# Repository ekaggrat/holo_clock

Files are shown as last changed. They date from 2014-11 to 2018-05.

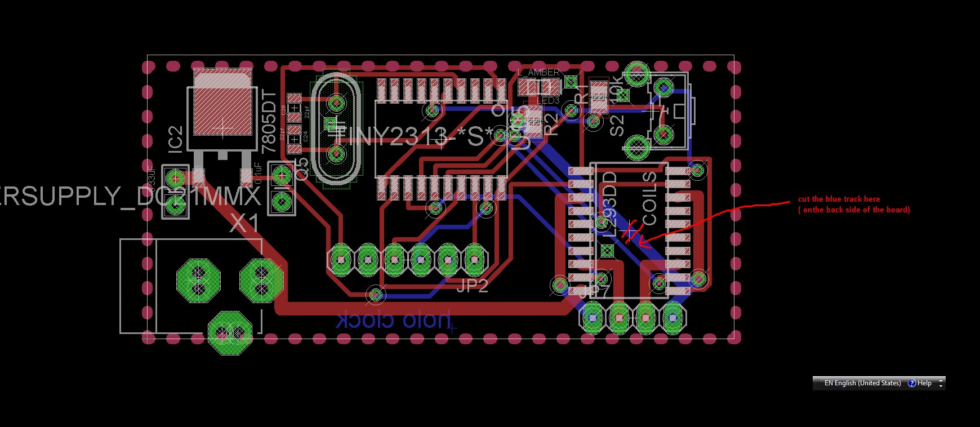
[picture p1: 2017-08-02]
pcb error.jpg

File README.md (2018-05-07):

View this project on [CADLAB.io](https://cadlab.io/node/990). 

holo_clock
==========
arduino and pcb files for holo clock

published
http://hackaday.com/2014/12/01/3d-printed-clock-tells-time-with-gears/

3d files here
http://www.thingiverse.com/thing:570797

for sale here
https://www.tindie.com/products/ekaggrat/holo-clock-2/

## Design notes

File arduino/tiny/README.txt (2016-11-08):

Arduino-Tiny is an open source set of ATtiny "cores" for the Arduino platform.

The Arduino platform currently supports Atmel ATmega processors. There is a need
for the Arduino platform to work with physically smaller DIP package processors.
The intent of this project is fulfill that need. Specifically, our goal is to
provide a core that enables Arduino users to work with the ATtiny84 (84/44/24),
ATtiny85 (85/45/25), and ATtiny2313 processors.

For more information about Arduino, see the website at: http://www.arduino.cc/

INSTALLATION

First ensure the Arduino software is correctly installed.

Next...

* Ensure the Arduino IDE is NOT running.

* Download the Arduino-Tiny archive (ZIP-file).

* Locate the Arduino Sketchbook folder.  This is the folder where the Arduino 
  IDE stores Sketches.

* Ensure the "hardware" folder exists under the Arduino Sketchbook folder.  For
  example, if the Arduino Sketchbook folder is...

      C:\Projects\Arduino\

  Ensure this folder exists...

      C:\Projects\Arduino\hardware\

* Extract the contents of the archive into the "hardware" folder.  For example,
  if the Arduino Sketchbook folder is...

      C:\Projects\Arduino

  After extracting, the following files / folders should exist...

      C:\Projects\Arduino\hardware\tiny\avr\license.txt
      C:\Projects\Arduino\hardware\tiny\avr\platform.txt
      C:\Projects\Arduino\hardware\tiny\avr\Prospective Boards.txt
      C:\Projects\Arduino\hardware\tiny\avr\README
      C:\Projects\Arduino\hardware\tiny\avr\bootloaders\
      C:\Projects\Arduino\hardware\tiny\avr\cores\

  The following folder should contain the source files for the Arduino-Tiny
  core...

      C:\Projects\Arduino\hardware\tiny\avr\cores\tiny\

* Create a new file named "boards.txt" in the tiny\avr directory.  Following 
  from the examples above, the file would be here...

      C:\Projects\Arduino\hardware\tiny\avr\boards.txt

* Open the "boards.txt" file and the "Prospective Boards.txt" file using your
  favourite text editor.

* Copy board entries of interest from "Prospective Boards.txt" to "boards.txt"
  (or copy the entire contents of "Prospective Boards.txt" to "boards.txt").
  Board entries are delineated by a long line of pound-signs.

* In the "boards.txt" file, change the "upload.tool" entries to the
  appropriate value for your setup.

* Save and close "boards.txt".  Close "Prospective Boards.txt".

* Start the Arduino IDE and ensure the new boards of interest are listed under
  the [Tools] [Board] menu...

      "ATtiny84 @ 16 MHz  (external crystal; 4.3 V BOD)"
      "ATtiny85 @ 8 MHz  (internal oscillator; BOD disabled)"
      etcetera

You are now ready to use Arduino-Tiny!

CREDITS

Arduino is an open source project, supported by many.

The Arduino team is composed of Massimo Banzi, David Cuartielles, Tom Igoe,
Gianluca Martino, and David A. Mellis.

Arduino uses the GNU avr-gcc toolchain, avrdude, avr-libc, and code from
Processing and Wiring.

Arduino-Tiny is based on work by David A. Mellis, René Bohne, R. Wiersma,
Alessandro Saporetti, and Brian Cook.

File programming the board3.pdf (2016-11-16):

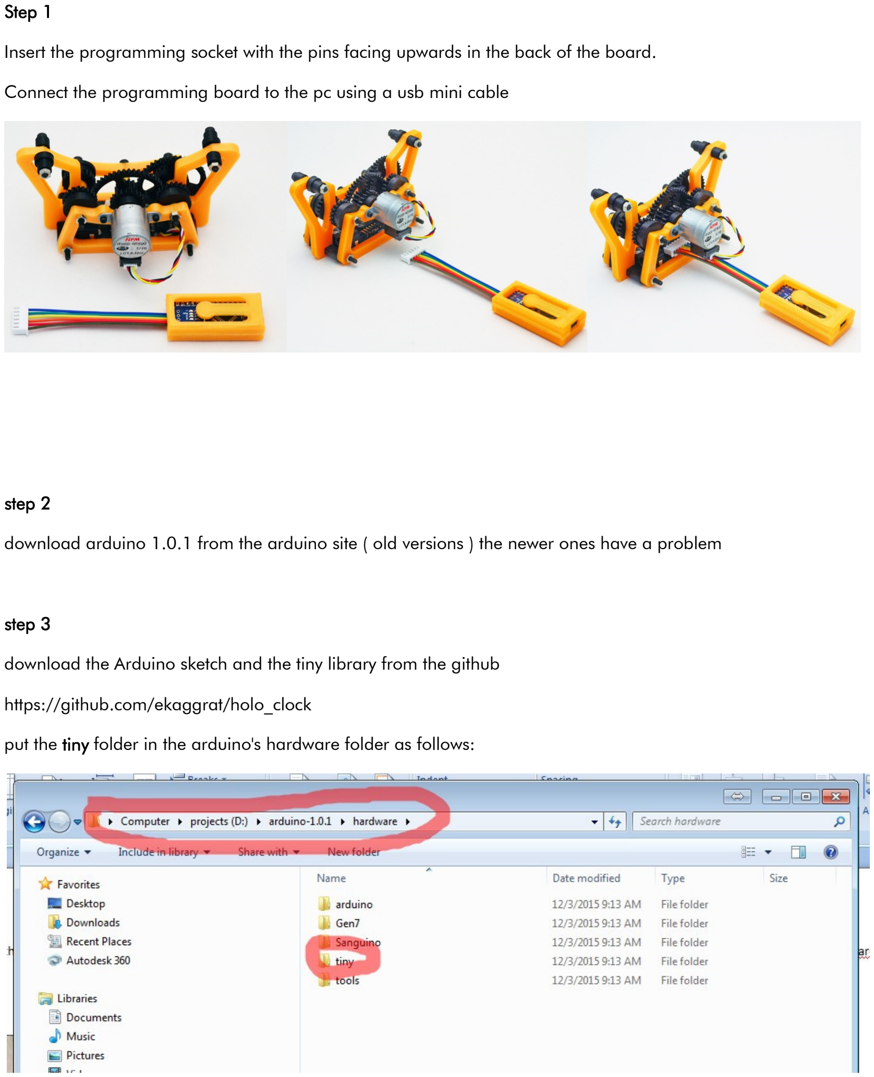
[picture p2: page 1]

Step 1

Insert the programming socket with the pins facing upwards in the back of the board.

Connect the programming board to the pc using a usb mini cable

step 2

download arduino 1.0.1 from the arduino site ( old versions ) the newer ones have a problem

step 3

download the Arduino sketch and the tiny library from the github

https://github.com/ekaggrat/holo_clock

put the tiny folder in the arduino's hardware folder as follows:

step 4

open the arduino 1.0.1 and the boards list now you should see attiny as follows

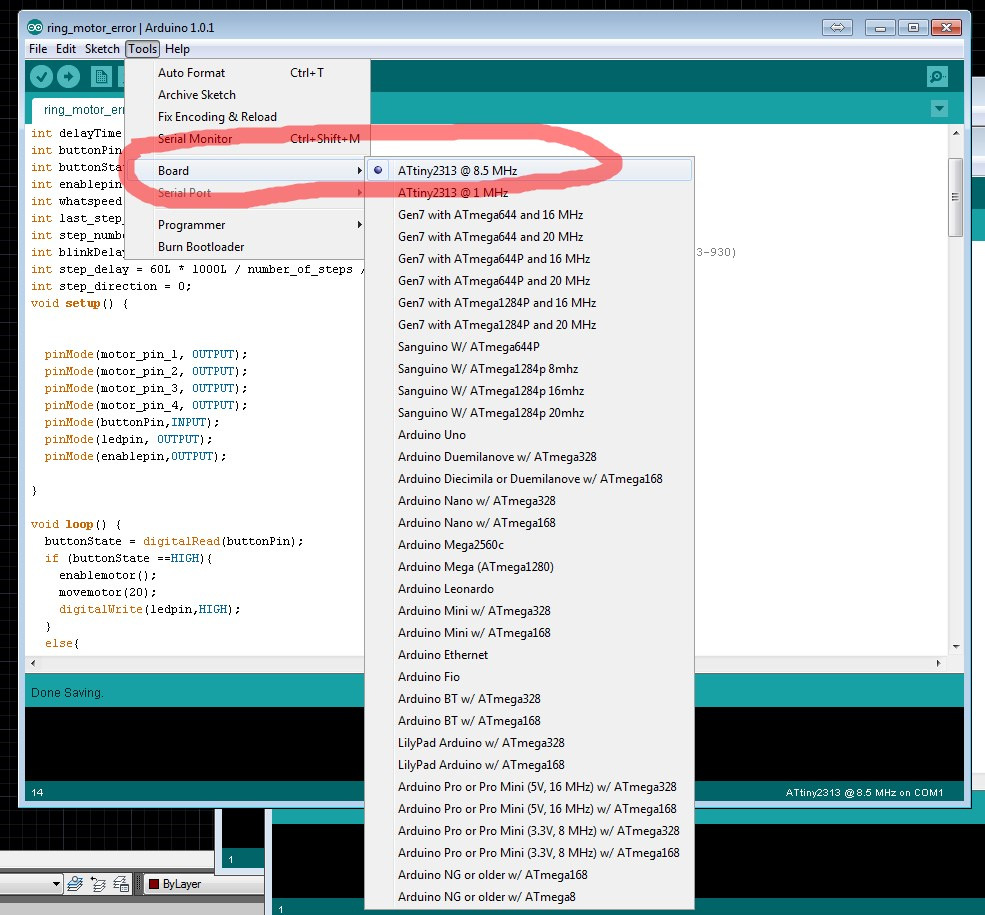
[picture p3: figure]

if not check the tiny folder is in the right location

step 7

open the Arduino sketch

upload the sketch using the following method.. ( dont upload as usual because that will not work ) First select the board as

attiny2313@ 8.5 . then upload using programmer

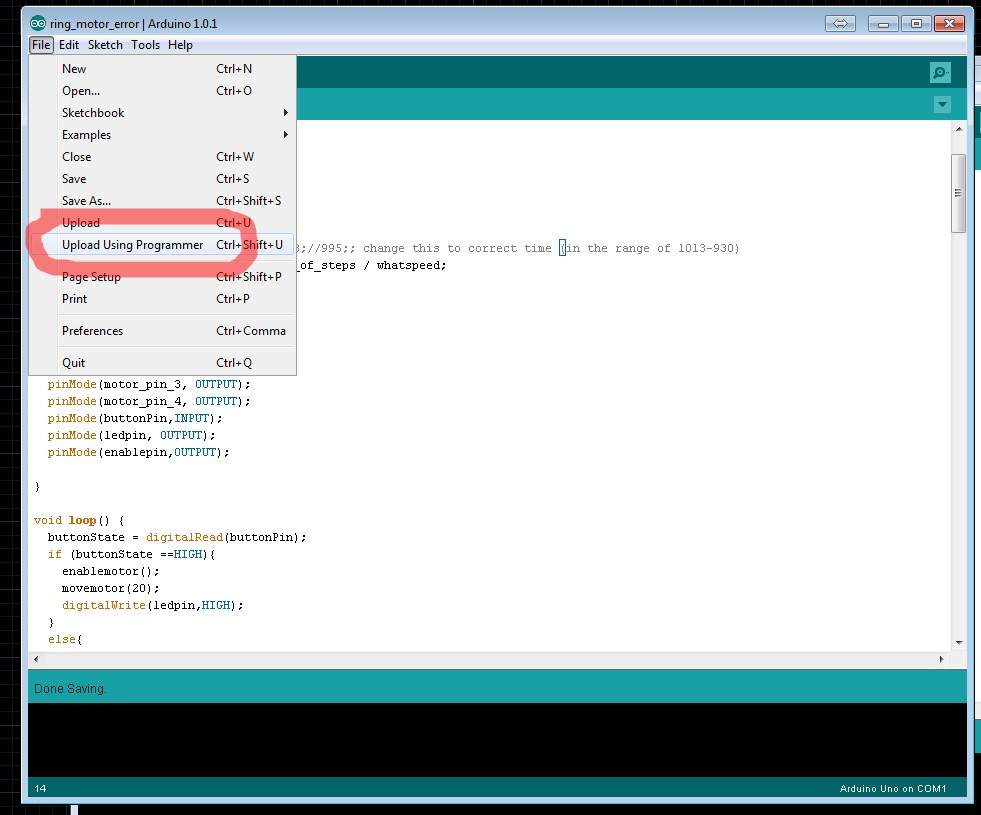
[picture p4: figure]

should be done ..

On the first go it might not upload. Just press the reset button on the programmer and try again.( this is a bug in Arduino )

step 8

If the clock is gaining or loosing time adjust the timing by changing the value for the last move

A value of 5 works well but it can vary depending on the power supply used.

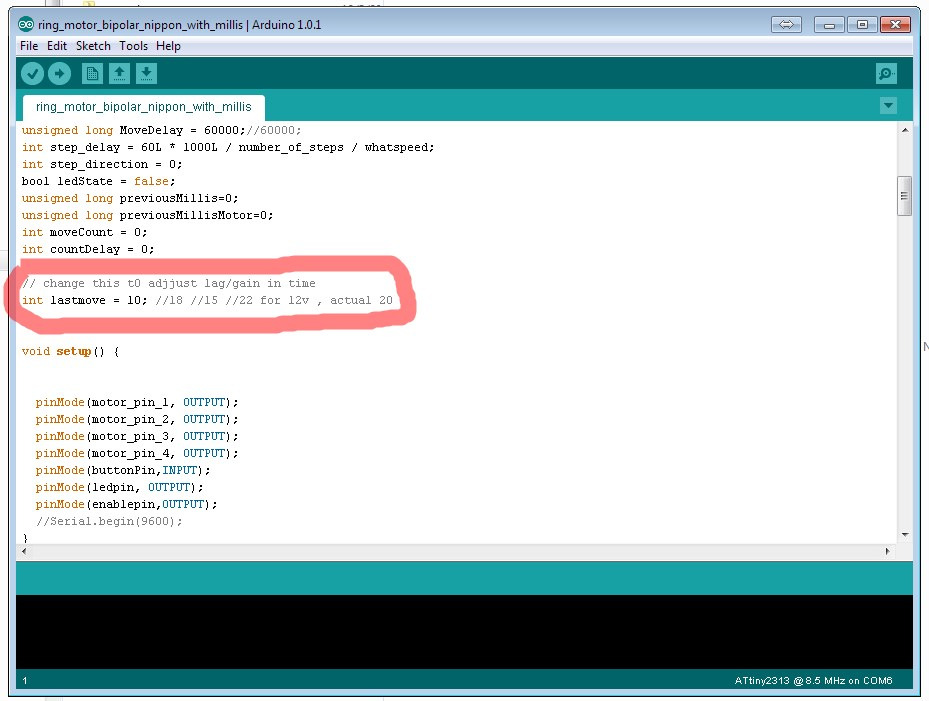
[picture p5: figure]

That’s it . the clock should be working fine now

To adjust the time just press the button on the left side and wait patiently for the needles to reach the correct position.

The clock only moves to change minutes and hours. The rest of the time it just blinks quietly to indicate seconds.

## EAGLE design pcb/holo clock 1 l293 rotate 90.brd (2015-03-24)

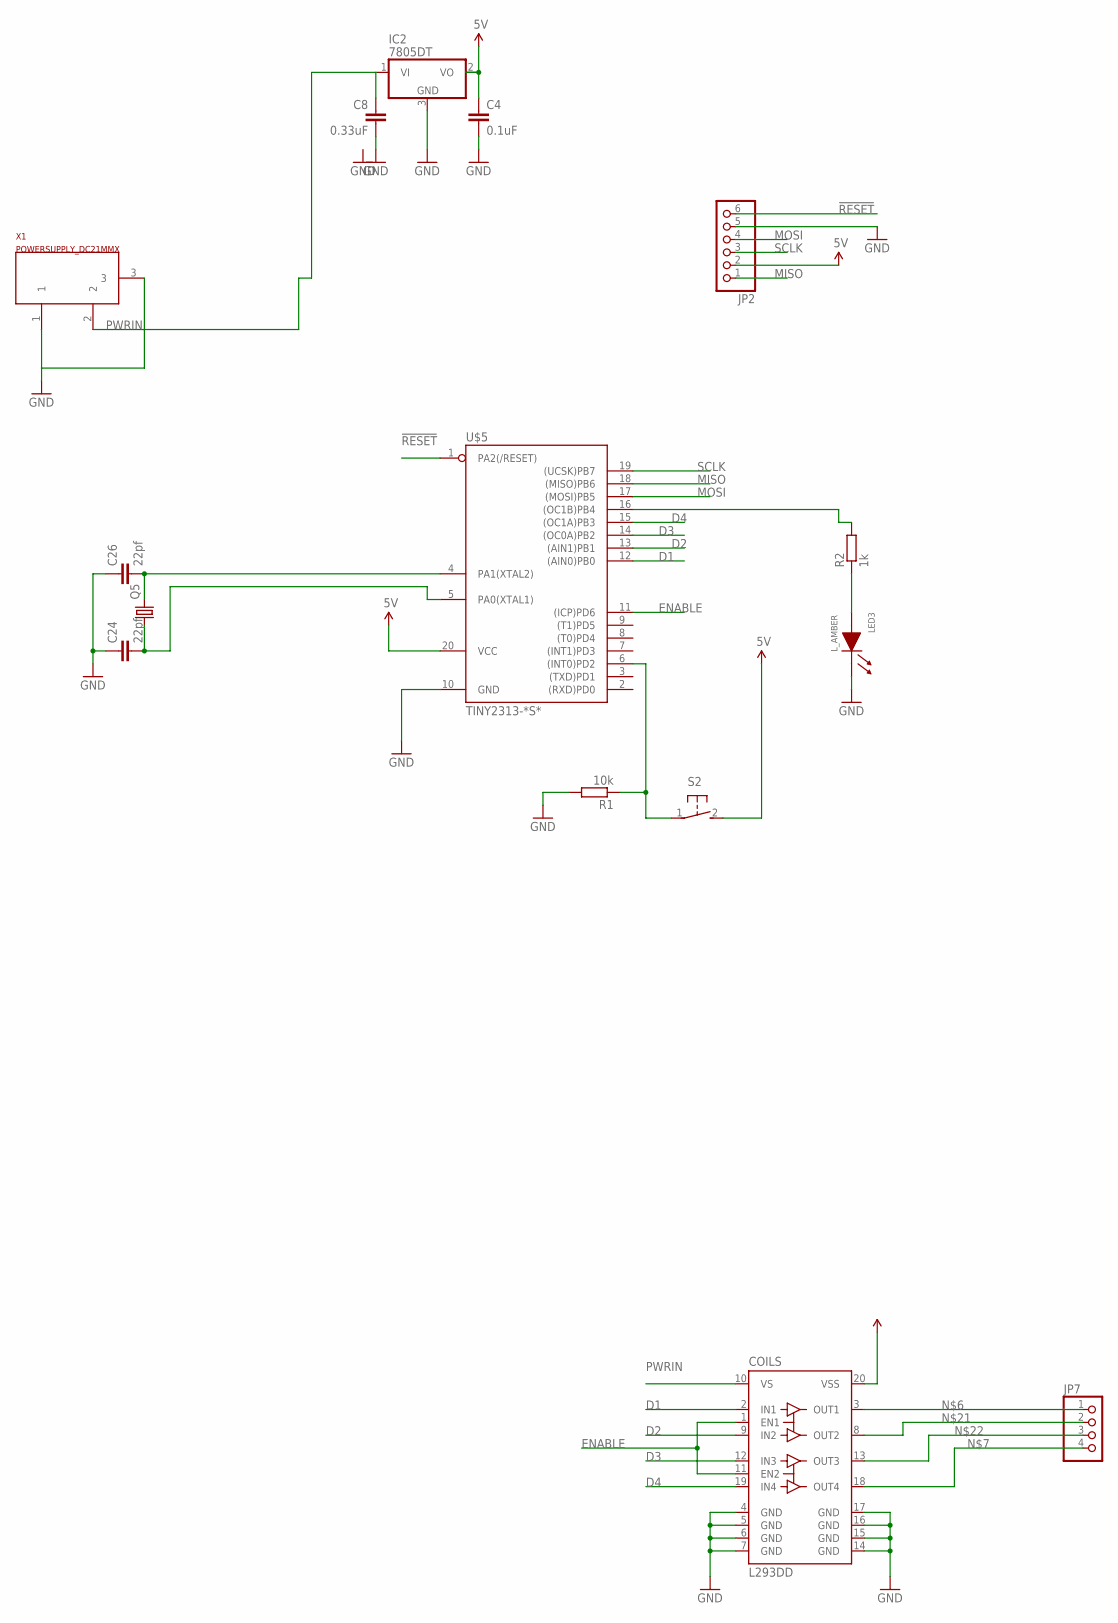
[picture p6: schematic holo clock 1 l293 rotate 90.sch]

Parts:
C4: 0.1uF; CAP-PTH-SMALL2
C8: 0.33uF; CAP-PTH-SMALL2
C24, C26: 22pf; 0805
COILS: L293DD; SO20
IC2: 7805DT; TO252
JP2: PINHD-1X6; 1X06
JP7: PINHD-1X04_2.54; 1X04
LED3: L_AMBER; LED0805
Q5: CRYSTALHC49S; HC49/S
R1: 10k; R0805
R2: 1k; R0805
S2: 31-XX; B3F-31XX
U$5: TINY2313-*S*; SO20L$
X1: POWERSUPPLY_DC21MMX; POWERSUPPLY_DC-21MM

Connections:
5V: C4.1, COILS.20 (VSS), IC2.2 (VO), JP2.2, S2.2 (S), U$5.20 (VCC)
!RESET: JP2.6, U$5.1 (PA2(/RESET))
D1: COILS.2 (IN1), U$5.12 ((AIN0)PB0)
D2: COILS.9 (IN2), U$5.13 ((AIN1)PB1)
D3: COILS.12 (IN3), U$5.14 ((OC0A)PB2)
D4: COILS.19 (IN4), U$5.15 ((OC1A)PB3)
ENABLE: COILS.1 (EN1), COILS.11 (EN2), U$5.11 ((ICP)PD6)
GND: C4.2, C8.2, C24.1, C26.1, COILS.4 (GND), COILS.5 (GND), COILS.6 (GND), COILS.7 (GND), COILS.14 (GND), COILS.15 (GND), COILS.16 (GND), COILS.17 (GND), IC2.3 (GND), JP2.5, LED3.1 (CA), R1.2, U$5.10 (GND), X1.1, X1.3
MISO: JP2.1, U$5.18 ((MISO)PB6)
MOSI: JP2.4, U$5.17 ((MOSI)PB5)
unnamed: R2.2, U$5.16 ((OC1B)PB4)
unnamed: COILS.3 (OUT1), JP7.1
unnamed: COILS.18 (OUT4), JP7.4, LED3.2 (AN), R2.1
unnamed: R1.1, S2.1, U$5.6 ((INT0)PD2)
unnamed: COILS.8 (OUT2), JP7.2
unnamed: COILS.13 (OUT3), JP7.3
unnamed: C26.2, Q5.2, U$5.4 (PA1(XTAL2))
unnamed: C24.2, Q5.1, U$5.5 (PA0(XTAL1))
PWRIN: C8.1, COILS.10 (VS), IC2.1 (VI), X1.2
SCLK: JP2.3, U$5.19 ((UCSK)PB7)

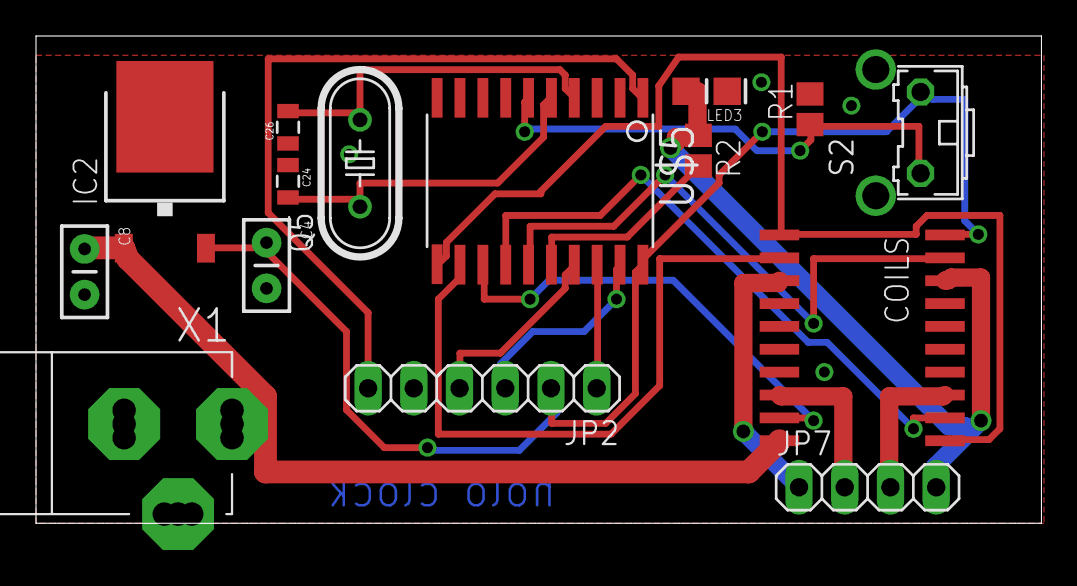
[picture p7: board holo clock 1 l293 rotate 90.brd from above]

Board: 2 copper layers, 55.9 x 27.1 mm, 15 parts (0 on the bottom side), 20 nets.

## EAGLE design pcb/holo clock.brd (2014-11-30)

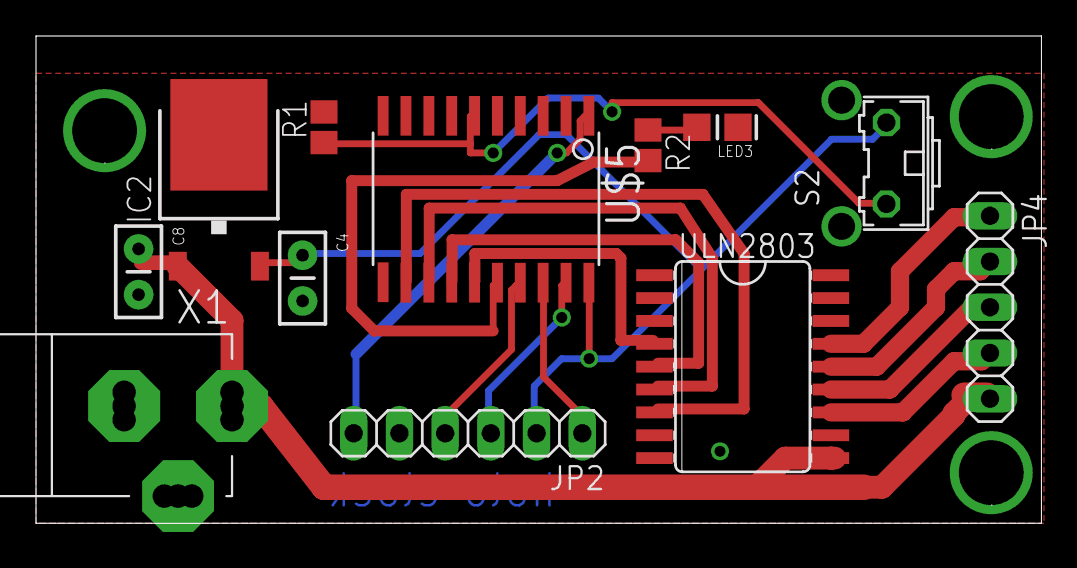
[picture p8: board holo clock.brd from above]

Board: 2 copper layers, 55.9 x 27.1 mm, 15 parts (0 on the bottom side), 18 nets.

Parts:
C4: 0.1uF; CAP-PTH-SMALL2
C8: 0.33uF; CAP-PTH-SMALL2
IC2: 7805DT; TO252
JP2: 1X06
JP4: 1X05
LED3: L_AMBER; LED0805
R1: 10k; R0805
R2: 1k; R0805
S2: B3F-31XX
U$5: TINY2313-*S*; SO20L$
U$14, U$17, U$18: PLATED-SCREW; PLATEDSCREW
ULN2803: ULN2803; SO18L
X1: POWERSUPPLY_DC21MMX; POWERSUPPLY_DC-21MM

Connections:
5V: C4.1, IC2.2, JP2.2, S2.2, U$5.20
!RESET: JP2.6, U$5.1
D1: U$5.12, ULN2803.7
D2: U$5.13, ULN2803.6
D3: U$5.14, ULN2803.5
D4: U$5.15, ULN2803.4
GND: C4.2, C8.2, IC2.3, JP2.5, LED3.1, R1.2, U$5.10, U$14.GND, U$17.GND, U$18.GND, ULN2803.9, X1.1, X1.3
MISO: JP2.1, U$5.18
MOSI: JP2.4, U$5.17
unnamed: JP4.1, ULN2803.15
unnamed: R2.2, U$5.16
unnamed: JP4.2, ULN2803.14
unnamed: JP4.3, ULN2803.13
unnamed: JP4.4, ULN2803.12
unnamed: LED3.2, R2.1
unnamed: R1.1, S2.1, U$5.6
PWRIN: C8.1, IC2.1, JP4.5, ULN2803.10, X1.2
SCLK: JP2.3, U$5.19

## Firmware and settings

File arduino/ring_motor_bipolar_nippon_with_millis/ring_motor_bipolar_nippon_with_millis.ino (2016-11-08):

//teeth in big gear 178
// teeth in small gear 20
// gear ratio 8.9
// motor steps per revolution 400

int number_of_steps = 200;
int motor_pin_1 = 9;
int motor_pin_2 = 10;
int motor_pin_3 = 11;
int motor_pin_4 = 12;
int ledpin = 13;
int delayTime = 4;
int buttonPin = 4;
int buttonState = 0; 
int enablepin = 8;
int whatspeed = 40;
int last_step_time =0;
int step_number = 0;
int blinkDelay = 1000;
unsigned long MoveDelay = 60000;//60000;
int step_delay = 60L * 1000L / number_of_steps / whatspeed;
int step_direction = 0;
bool ledState = false;
unsigned long previousMillis=0;
unsigned long previousMillisMotor=0;
int moveCount = 0;
int countDelay = 0;

// change this t0 adjjust lag/gain in time
int lastmove = 5; //22 for 12v , actual 20


void setup() {


  pinMode(motor_pin_1, OUTPUT);
  pinMode(motor_pin_2, OUTPUT);
  pinMode(motor_pin_3, OUTPUT);
  pinMode(motor_pin_4, OUTPUT);
  pinMode(buttonPin,INPUT);
  pinMode(ledpin, OUTPUT);
  pinMode(enablepin,OUTPUT);
  //Serial.begin(9600);
}

void loop() {
  buttonState = digitalRead(buttonPin);
  blinkk();
  if (buttonState ==HIGH){
    enablemotor();
    movemotor(20);
    digitalWrite(ledpin,HIGH);
  }
  else{
    
    unsigned long currentMillisMotor = millis();

    if ((unsigned long)(currentMillisMotor - previousMillisMotor) >=MoveDelay) {
enablemotor();
      if ( moveCount >= 58){
        movemotor(lastmove);//22//23//25
        moveCount = 0;
      }
      else {

        movemotor(15);
        moveCount = moveCount + 1;
      }
      motoroff();
      previousMillisMotor = currentMillisMotor;
    }


    motoroff();

  }

}



void enablemotor(){
  digitalWrite(enablepin,HIGH);
}


void movestep(int steps_to_move){
  int steps_left = abs(steps_to_move);

  if (steps_to_move > 0) { 
    step_direction = 1;
  }
  if (steps_to_move < 0) { 
    step_direction = 0;
  }


  while(steps_left > 0) {
    // if (millis() - last_step_time >= step_delay ) {
    //last_step_time = millis();
    if ( step_direction == 1 ){
      step_number++;
      delay(step_delay);
      if (step_number == number_of_steps) {
        step_number = 0;
      }
    }
    else {
      if (step_number ==0){
        step_number = number_of_steps;
      }
      step_number--;
    }
    steps_left--;


    stepmotor(step_number % 4);


    //} 
  }
}





void stepmotor(int thisStep){

  switch (thisStep) {
  case 0:    // 1010
    digitalWrite(motor_pin_1, HIGH);
    digitalWrite(motor_pin_2, LOW);
    digitalWrite(motor_pin_3, HIGH);
    digitalWrite(motor_pin_4, LOW);
    break;
  case 1:    // 0110
    digitalWrite(motor_pin_1, LOW);
    digitalWrite(motor_pin_2, HIGH);
    digitalWrite(motor_pin_3, HIGH);
    digitalWrite(motor_pin_4, LOW);
    break;
  case 2:    //0101
    digitalWrite(motor_pin_1, LOW);
    digitalWrite(motor_pin_2, HIGH);
    digitalWrite(motor_pin_3, LOW);
    digitalWrite(motor_pin_4, HIGH);
    break;
  case 3:    //1001
    digitalWrite(motor_pin_1, HIGH);
    digitalWrite(motor_pin_2, LOW);
    digitalWrite(motor_pin_3, LOW);
    digitalWrite(motor_pin_4, HIGH);
    break;
  } 

}

void blinkk(){

  unsigned long currentMillis = millis();
  //motoroff();
  if ((unsigned long)(currentMillis - previousMillis) >= blinkDelay) {

    ledState = !ledState; 
    digitalWrite(ledpin, ledState); 

    previousMillis = currentMillis;
  } 

}

void motoroff(){
  digitalWrite(enablepin,LOW);
  digitalWrite(motor_pin_1, LOW);
  digitalWrite(motor_pin_2, LOW);
  digitalWrite(motor_pin_3, LOW);
  digitalWrite(motor_pin_4, LOW);
}

void movemotor(int m){

  for (int x=0; x< m;x++){ 
    digitalWrite(motor_pin_1, HIGH);
    digitalWrite(motor_pin_2, LOW);
    digitalWrite(motor_pin_3, HIGH);
    digitalWrite(motor_pin_4, LOW);
    delay(step_delay);
    digitalWrite(motor_pin_1, LOW);
    digitalWrite(motor_pin_2, HIGH);
    digitalWrite(motor_pin_3, HIGH);
    digitalWrite(motor_pin_4, LOW);
    delay(step_delay);
    digitalWrite(motor_pin_1, LOW);
    digitalWrite(motor_pin_2, HIGH);
    digitalWrite(motor_pin_3, LOW);
    digitalWrite(motor_pin_4, HIGH);
    delay(step_delay);
    digitalWrite(motor_pin_1, HIGH);
    digitalWrite(motor_pin_2, LOW);
    digitalWrite(motor_pin_3, LOW);
    digitalWrite(motor_pin_4, HIGH);
    delay(step_delay);
  }
}

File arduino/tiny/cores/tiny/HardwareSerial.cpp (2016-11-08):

/*
  HardwareSerial.cpp - Hardware serial library for Wiring
  Copyright (c) 2006 Nicholas Zambetti.  All right reserved.

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
  Modified 23 November 2006 by David A. Mellis
  Modified 28 September 2010 by Mark Sproul
*/

#include <stdlib.h>
#include <stdio.h>
#include <string.h>
#include <inttypes.h>

#include "core_build_options.h"
#include "wiring.h"
#include "wiring_private.h"

// this next line disables the entire HardwareSerial.cpp,
// this is so I can support Attiny series and any other chip without a uart
#if defined(UBRRH) || defined(UBRR0H) || defined(UBRR1H) || defined(UBRR2H) || defined(UBRR3H)

#include "HardwareSerial.h"

// Define constants and variables for buffering incoming serial data.  We're
// using a ring buffer (I think), in which rx_buffer_head is the index of the
// location to which to write the next incoming character and rx_buffer_tail
// is the index of the location from which to read.
#if (RAMEND < 1000)
  #define RX_BUFFER_SIZE 32
#else
  #define RX_BUFFER_SIZE 128
#endif

struct ring_buffer
{
  unsigned char buffer[RX_BUFFER_SIZE];
  int head;
  int tail;
};

#if defined(UBRRH) || defined(UBRR0H)
  ring_buffer rx_buffer  =  { { 0 }, 0, 0 };
#endif
#if defined(UBRR1H)
  ring_buffer rx_buffer1  =  { { 0 }, 0, 0 };
#endif
#if defined(UBRR2H)
  ring_buffer rx_buffer2  =  { { 0 }, 0, 0 };
#endif
#if defined(UBRR3H)
  ring_buffer rx_buffer3  =  { { 0 }, 0, 0 };
#endif

inline void store_char(unsigned char c, ring_buffer *rx_buffer)
{
  int i = (unsigned int)(rx_buffer->head + 1) % RX_BUFFER_SIZE;

  // if we should be storing the received character into the location
  // just before the tail (meaning that the head would advance to the
  // current location of the tail), we're about to overflow the buffer
  // and so we don't write the character or advance the head.
  if (i != rx_buffer->tail) {
    rx_buffer->buffer[rx_buffer->head] = c;
    rx_buffer->head = i;
  }
}

#if defined(USART_RX_vect)
  ISR(USART_RX_vect)
  {
  #if defined(UDR0)
    unsigned char c  =  UDR0;
  #elif defined(UDR)
    unsigned char c  =  UDR;  //  atmega8535
  #else
    #error UDR not defined
  #endif
    store_char(c, &rx_buffer);
  }
#elif defined(USART0_RECV_vect) && defined(UDR0)
  ISR(USART0_RECV_vect)
  {
    unsigned char c  =  UDR0;
    store_char(c, &rx_buffer);
  }
#elif defined(UART0_RECV_vect) && defined(UDR0)
  ISR(UART0_RECV_vect)
  {
    unsigned char c  =  UDR0;
    store_char(c, &rx_buffer);
  }
//#elif defined(SIG_USART_RECV)
#elif defined(USART0_RX_vect)
  // fixed by Mark Sproul this is on the 644/644p
  //ISR(SIG_USART_RECV)
  ISR(USART0_RX_vect)
  {
  #if defined(UDR0)
    unsigned char c  =  UDR0;
  #elif defined(UDR)
    unsigned char c  =  UDR;  //  atmega8, atmega32
  #else
    #error UDR not defined
  #endif
    store_char(c, &rx_buffer);
  }
#elif defined(UART_RECV_vect)
  // this is for atmega8
  ISR(UART_RECV_vect)
  {
  #if defined(UDR0)
    unsigned char c  =  UDR0;  //  atmega645
  #elif defined(UDR)
    unsigned char c  =  UDR;  //  atmega8
  #endif
    store_char(c, &rx_buffer);
  }
#elif defined(USBCON)
  #warning No interrupt handler for usart 0
  #warning Serial(0) is on USB interface
#else
  #error No interrupt handler for usart 0
#endif

//#if defined(SIG_USART1_RECV)
#if defined(USART1_RX_vect)
  //ISR(SIG_USART1_RECV)
  ISR(USART1_RX_vect)
  {
    unsigned char c = UDR1;
    store_char(c, &rx_buffer1);
  }
#endif

#if defined(USART2_RX_vect) && defined(UDR2)
  ISR(USART2_RX_vect)
  {
    unsigned char c = UDR2;
    store_char(c, &rx_buffer2);
  }
#endif

#if defined(USART3_RX_vect) && defined(UDR3)
  ISR(USART3_RX_vect)
  {
    unsigned char c = UDR3;
    store_char(c, &rx_buffer3);
  }
#endif



// Constructors ////////////////////////////////////////////////////////////////

HardwareSerial::HardwareSerial(ring_buffer *rx_buffer,
  volatile uint8_t *ubrrh, volatile uint8_t *ubrrl,
  volatile uint8_t *ucsra, volatile uint8_t *ucsrb,
  volatile uint8_t *udr,
  uint8_t rxen, uint8_t txen, uint8_t rxcie, uint8_t udre, uint8_t u2x)
{
  _rx_buffer = rx_buffer;
  _ubrrh = ubrrh;
  _ubrrl = ubrrl;
  _ucsra = ucsra;
  _ucsrb = ucsrb;
  _udr = udr;
  _rxen = rxen;
  _txen = txen;
  _rxcie = rxcie;
  _udre = udre;
  _u2x = u2x;
}

// Public Methods //////////////////////////////////////////////////////////////

void HardwareSerial::begin(long baud)
{
  uint16_t baud_setting;
  bool use_u2x = true;

#if F_CPU == 16000000UL
  // hardcoded exception for compatibility with the bootloader shipped
  // with the Duemilanove and previous boards and the firmware on the 8U2
  // on the Uno and Mega 2560.
  if (baud == 57600) {
    use_u2x = false;
  }
#endif
  
  if (use_u2x) {
    *_ucsra = 1 << _u2x;
    baud_setting = (F_CPU / 4 / baud - 1) / 2;
  } else {
    *_ucsra = 0;
    baud_setting = (F_CPU / 8 / baud - 1) / 2;
  }

  // assign the baud_setting, a.k.a. ubbr (USART Baud Rate Register)
  *_ubrrh = baud_setting >> 8;
  *_ubrrl = baud_setting;

  sbi(*_ucsrb, _rxen);
  sbi(*_ucsrb, _txen);
  sbi(*_ucsrb, _rxcie);
}

void HardwareSerial::end()
{
  cbi(*_ucsrb, _rxen);
  cbi(*_ucsrb, _txen);
  cbi(*_ucsrb, _rxcie);  
}

int HardwareSerial::available(void)
{
  return (unsigned int)(RX_BUFFER_SIZE + _rx_buffer->head - _rx_buffer->tail) % RX_BUFFER_SIZE;
}

int HardwareSerial::peek(void)
{
  if (_rx_buffer->head == _rx_buffer->tail) {
    return -1;
  } else {
    return _rx_buffer->buffer[_rx_buffer->tail];
  }
}

int HardwareSerial::read(void)
{
  // if the head isn't ahead of the tail, we don't have any characters
  if (_rx_buffer->head == _rx_buffer->tail) {
    return -1;
  } else {
    unsigned char c = _rx_buffer->buffer[_rx_buffer->tail];
    _rx_buffer->tail = (unsigned int)(_rx_buffer->tail + 1) % RX_BUFFER_SIZE;
    return c;
  }
}

void HardwareSerial::flush()
{
  // don't reverse this or there may be problems if the RX interrupt
  // occurs after reading the value of rx_buffer_head but before writing
  // the value to rx_buffer_tail; the previous value of rx_buffer_head
  // may be written to rx_buffer_tail, making it appear as if the buffer
  // don't reverse this or there may be problems if the RX interrupt
  // occurs after reading the value of rx_buffer_head but before writing
  // the value to rx_buffer_tail; the previous value of rx_buffer_head
  // may be written to rx_buffer_tail, making it appear as if the buffer
  // were full, not empty.
  _rx_buffer->head = _rx_buffer->tail;
}

size_t HardwareSerial::write(uint8_t c)
{
  while (!((*_ucsra) & (1 << _udre)))
    ;

  *_udr = c;

  return( 1 );
}

// Preinstantiate Objects //////////////////////////////////////////////////////
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

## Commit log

2014-11-30 pcb and ino
    [holo clock attiny with buttons rotate 90.brd, holo clock attiny with buttons rotate 90.sch]
2014-12-02 added crystal to pcb
    [holo clock add crystal.brd, holo clock add crystal.sch]
2015-02-12 final pcb
    [holo clock 1.brd, holo clock 1.sch, holo clock add crystal.brd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]
2015-03-24 bipolar motor
2015-03-24 bipolar motor pcb
    [holo clock 1 l293 rotate 90.brd, holo clock 1 l293 rotate 90.sch]
2017-08-02 pcb track error
    please see this if you make the pcb. The track on the back side of the board needs to be cut or the led will get short.
